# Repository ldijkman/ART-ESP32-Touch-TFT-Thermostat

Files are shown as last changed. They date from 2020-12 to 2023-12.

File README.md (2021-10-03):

# ART-ESP32-Touch-TFT-Thermostat

https://gofund.me/b8bf0b52

ART ESP32 SPI TFT Touch Clock Thermostat	

Manual by Touch TFT and WIFI(Future) clock thermostat

10 dollar DIY NEST thermostat	

Art, A Better NEST	

&&&&&&&&&&&&&&&&&&&&&&&&&&&&&&&&&&&&&&&&&&&&&&&&&&&&&&&&&&&&&&&&&&&&&&&&&&&&&&

GNU General Public License,

which basically means that you may freely copy, change, and distribute it,

but you may not impose any restrictions on further distribution,

and you must make the source code available.

&&&&&&&&&&&&&&&&&&&&&&&&&&&&&&&&&&&&&&&&&&&&&&&&&&&&&&&&&&&&&&&&&&&&&&&&&&&&&

https://oshwlab.com/l.dijkman/esp32-dev-kit-38-pin-to-spi-touch-tft	

https://github.com/ldijkman/ART-ESP32-Touch-TFT-Thermostat	

https://www.youtube.com/user/LuberthDijkman/videos

https://m.facebook.com/groups/2643123052617990

https://www.facebook.com/groups/esp32smartthermostat

#
## A Part of Art => HardWare is described @
## https://oshwlab.com/l.dijkman/esp32-dev-kit-38-pin-to-spi-touch-tft

Let's make ART smart!

.	

.	
#	
# Start ART	

@[youtube](http://youtu.be/qNYT64CaLEI)	

Simple Looks, No OverKill (Maybe make it SkinAble, For Those who like OverKill)

OK Distracted https://www.youtube.com/watch?v=0U4r2_s59qk



ECO mode = continu low heat setpoint energy saving setpoint (14C?)

NORMAL mode = continu heat comfortable setpoint (21C?)

AUTO mode = Switch heat temperature on programmed times with temperature

COOL mode = continu setpoint cooling airco/ventilator (25C?)

Maybe i will add a WoodStove Mode  = every hour? gas central water heating on for 5? minutes 

i mostly heat on a wood stove wich makes it colder in other parts of the house

i open the doors so that the heat can spread

But with stormy ice cold eastern wind / storm pipes can freeze in my old house

@[youtube](http://youtu.be/qNYT64CaLEI)	

ART_ESP32_Thermostat	

@[youtube](http://youtu.be/qNYT64CaLEI)	

Future (Could use some help on the WiFiManger & WebServer / HTML WebPage Part)

	

https://jsfiddle.net/luberth/b6y53cn0	

FullScreen https://jsfiddle.net/luberth/b6y53cn0/embedded/result/#Result	

#	
## First time EasyEDA.com and JLCPCB.com and LCSC.com == Perfect!	

My ESP32 TFT prototype test board, extra row of female connnectors for connecting devices test pinout

Only the holes ar a bit tight, but female row headers fit => Next time, double side copper PCB

And Ground the copper poor infill

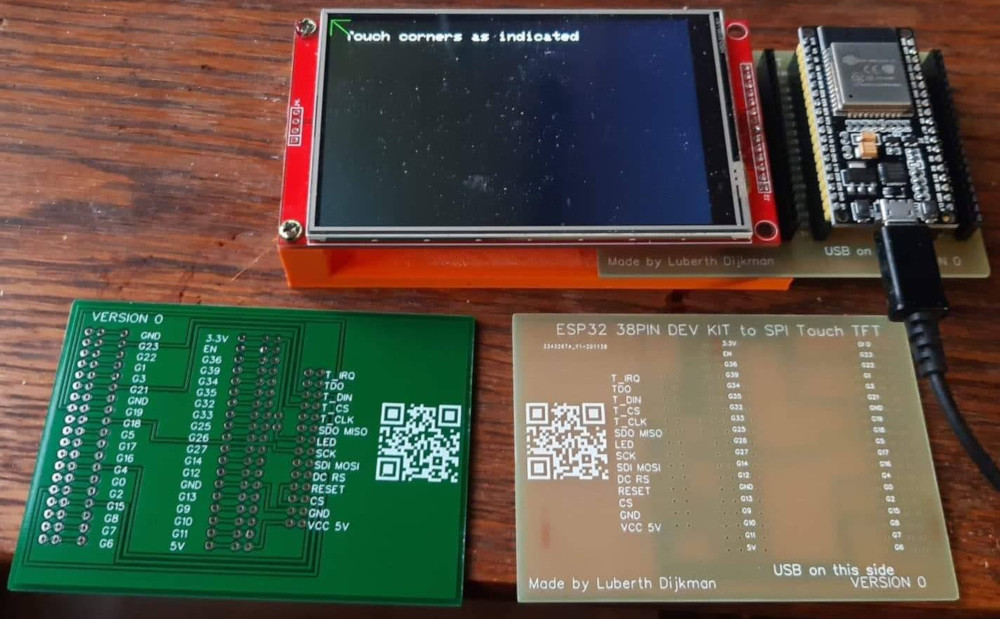
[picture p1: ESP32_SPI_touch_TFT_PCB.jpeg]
	

My ESP32 TFT prototype test board, extra row of female connnectors for connecting devices test pinout	

First time EasyEDA.com and JLCPCB.com and LCSC.com == Perfect!	

#
## DS3231 RTC with NTC Thermistor soldered onto power 

## sorry i switched to BME280 sensor temp. humid. barometer sensor == much better 

VCC on RTC DS3231 is 3.3V

Less Wires = Only a Signal wire from NTC Thermistor

NTC Connect => (-GND to VCC+3.3V) (VCC+3.3V to -GND) In Other Words Silkscreen print - should be + 

(This way its PULLDOWN) NTC Signal Line pulled down to ground
```diff
-Art's TFT screen will tell you how to connect the wires to ESP32 on startup

-On first boot Art's screen is Snowy for 20 seconds => I think Art is Formatting his Brain/Flash

```
ESP32 Note: Analog noise and fluctuences with analog read => multiread and capacitor 

https://docs.espressif.com/projects/esp-idf/en/latest/esp32/api-reference/peripherals/adc.html

Not so clear for me as DIY Tinker  => think they want a 0.1mf 100uf capacitor between signal and ground to damp the analog read

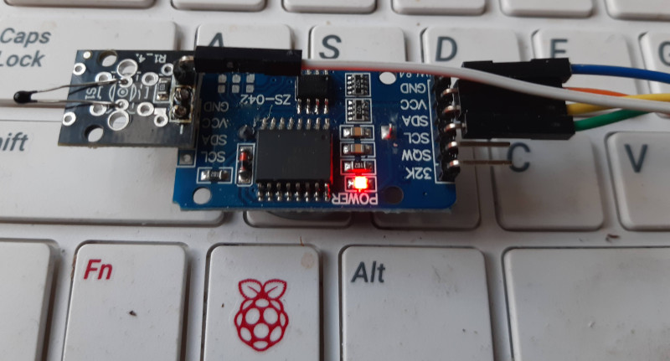
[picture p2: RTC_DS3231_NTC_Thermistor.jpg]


#
## TFT Backlight PWM cut the LED track to 3.3V

i have cut the LED track to 3.3V between the Pads

soldered a wire on the LED side pad

LED connected Wire connected to GPIO15 for the moment

Can now control the BackLight PWM from the screen/slidebar

in the LOOP{} is a hardcoded setting for now => dim screen if hour > ?? and < as ??

Jo's Energy Saver ;-)

a touch in top of screen in the blue rectangle => opens the settings menu

Blue border rectangle = Heating / Cooling is OFF

DutchOrange border Rectangle = The Heat is ON

IceBlue border Rectangle = Cooling is ON

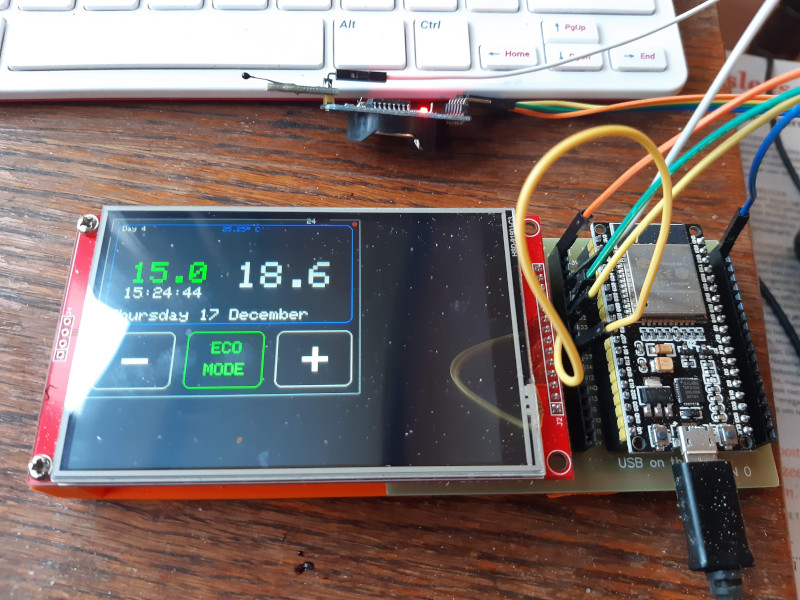
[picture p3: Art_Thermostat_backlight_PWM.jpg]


#
## Art output relais  heat & cool or single relais

the double relaiscoil is optical isolated swithed by optocoupler

the single relaiscoil is switched by transistor

a bit big relais for most off the time 24VAC CentralHeatingSystem switching

GND=GND

VCC = +5V (for the relais Coil) ESP32 +5VDC is comming from  USB

IN1, IN2 = if pulled low to GND => relais==ON (GPIO25 and GPIO26 from ESP32)

===== maybe Disconnect relais when programming ESP32  ======

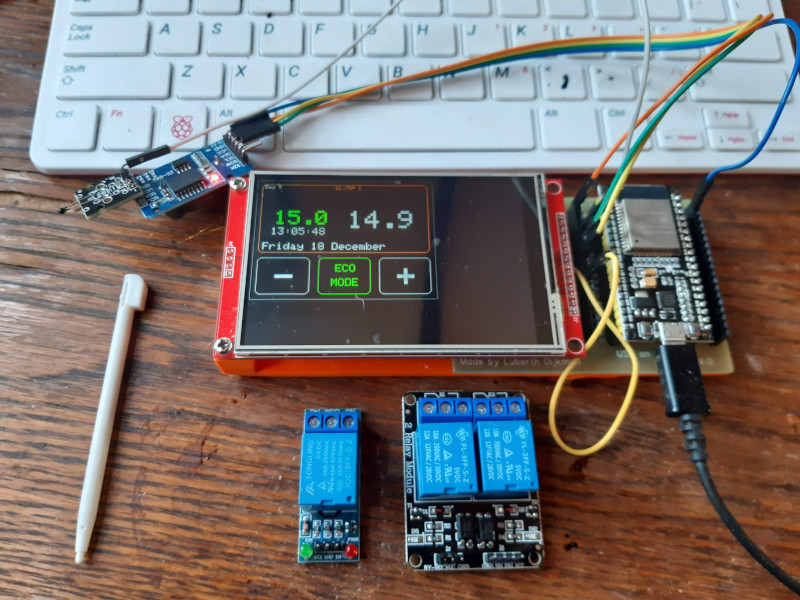
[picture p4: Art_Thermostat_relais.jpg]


#
## Art's Sensor BME280 Temperature, Humidity, Barometer (4Future)

ESP32 BME280 sensor test 

https://github.com/ldijkman/ART-ESP32-Touch-TFT-Thermostat/blob/main/test/ESP32_BME280_barometer_humidity_temperature_sensor_test.ino

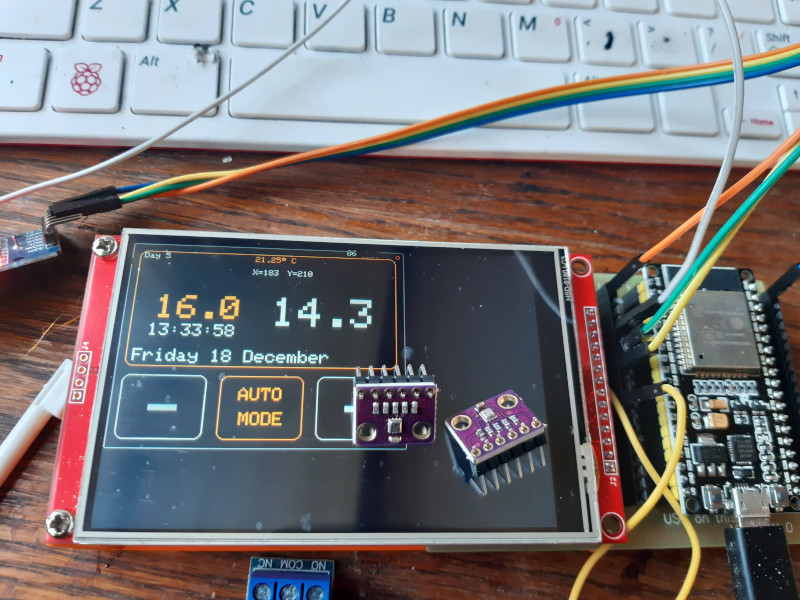
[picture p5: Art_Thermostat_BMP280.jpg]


#

BME280 humidity a scale makes vissible how whe ar doing with RV%

got my barometer pressure info from my pi webserver page http://84.107.155.75/

HE IS DAT HTTP://ARDUINO.Tk

## Art with Linear Humidity Comfort Scale 

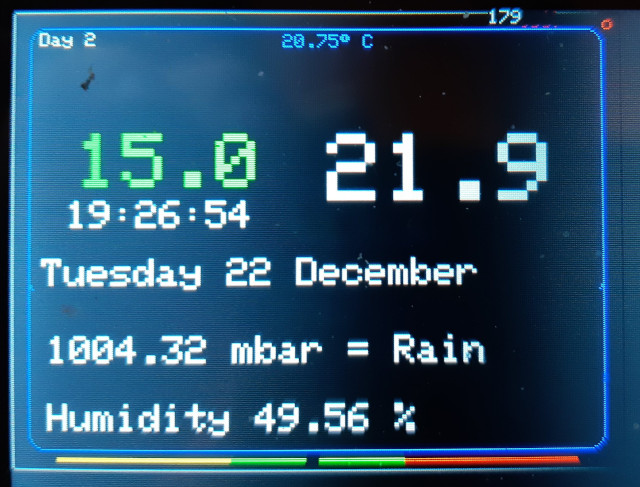
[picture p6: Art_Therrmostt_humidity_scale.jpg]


#
## Art with Linear BaroMeter and Humidity Comfort Scale

No it's not a slider, Art can not change the weather!

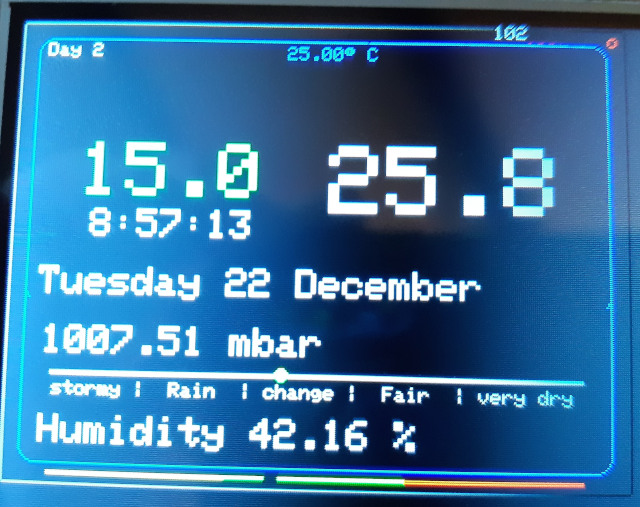
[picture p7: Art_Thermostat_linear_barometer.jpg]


#	
## This is wat your Arduino IDE should look like, Main File with the TAB files	

ART_ESP32_Thermostat_7_12_2020_ver2.ino => is the Main File	

The other *.INO files are included tab files (Should be in the same Directory as Main File)	

	

#
Have you got Arduino Experience, But don't know what to Do

WANTED, Boring Bored People or Students, I Could use some Help?!  ;-) 	

Make YourSelf UseFull!	

#

## It is Calendar Time, Free Printable Calender in many Languages	
## Print a Calendar for your Parents, GrandParents	
## http://sticker.tk/kalender.php
## http://arduino.tk
## http://PRINT-it.tk      
## http://PRINTit.tk

Art has a brand new home server http://www.arduino.tk

#
## maybe rtttl nokia ringtones for Art's Alarm 

http://Arduino.tk/rtttl/

http://Arduino.tk/rtttl/RTTTL_Tunes/ couple off thousands tunes 

We Dutch love Orange http://arduino.tk//rtttl/RTTTL_Tunes/play.php?file=Andr%E9+Hazes+-+Wij+Houden+Van+Oranje.txt

4 Art's BirthDay  http://sticker.tk/forum/rtttl/RTTTL_Tunes/play.php?file=Misc+-+Happy+Birthday+1.txt

dat mensen hier geld voor betaalden 
http://arduino.tk/rtttl/RTTTL_Tunes/play.php?file=xfiles.txt

#
### A Penny for Sharing My Thoughts?	

www.paypal.me/LDijkman	

# Art is now LIVE at http://Arduino.TK

# Help Art?!

https://m.facebook.com/groups/2643123052617990

https://www.facebook.com/groups/esp32smartthermostat

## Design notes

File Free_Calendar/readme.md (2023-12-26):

my mother had a paper memory

# Free printable calendar 2024

https://plnkr.co/plunk/2u0EyeybmaM9kdI8

Free_Printable_Calendar

https://plnkr.co/plunk/2u0EyeybmaM9kdI8

Screenshot from 2023-12-26 07-34-43

https://plnkr.co/plunk/2u0EyeybmaM9kdI8

http://PRINT-it.TK?v=dutch&year=2021

http://PRINT-it.TK?v=englisch&year=2021

more calendar versions/variants links in the video description https://youtu.be/yTHn8bYUQ8A

*.SKP is a web sketchup file a free online inbrowser 3D drawing program https://app.sketchup.com/app#

*.STL is for your Slic3r to generate G-Code for your 3d-printer

########################################################################################

SketchUp WEB OnLine inBrowser GETTING STARTED with SketchUp Free

BEGINNERS Start Here! https://www.youtube.com/watch?v=I_bJPNnO3HQ

How to create 3d model using sketchup web. (easy) https://youtu.be/4nKlk4asY6s .

Sketchup web 3d text tutorial https://www.youtube.com/watch?v=TQ_WKglHLcA

##########################################################################################

github STL 3D viewer 
https://github.com/ldijkman/ART-ESP32-Touch-TFT-Thermostat/blob/main/Free_Calendar/calendar_1_slic3r.stl

Want to make a 3d print / design for connecting / hang the printed calendar papers

 https://github.com/ldijkman/ART-ESP32-Touch-TFT-Thermostat/blob/main/Free_Calendar/calendar_1_(4).stl
 
 calendar_1_(4).stl with a steel / copper wire
 
 DutchOrange Hanger ;-)
 
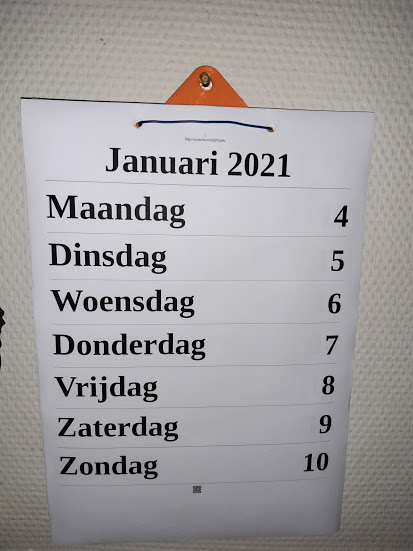
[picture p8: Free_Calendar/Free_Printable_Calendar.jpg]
 

 calendar_1_(4).stl with a steel / copper wire

http://PRINT-it.TK?v=dutch&year=2021

http://PRINT-it.TK?v=englisch&year=2021

kalender 1 day per a4 

http://sticker.tk/day_calender.php?v=dutch&year=2021

http://sticker.tk/day_calender.php?v=englisch&year=2021

http://sticker.tk/day_calender_portrait.php?v=dutch&year=2021

http://sticker.tk/day_calender_portrait.php?v=englisch&year=2021

week bigger days

http://sticker.tk/week_kalender.php?v=dutch&year=2021

http://sticker.tk/week_kalender.php?v=englisch&year=2021

week big days short

http://sticker.tk/week_kalender_afk.php?v=dutch&year=2021

http://sticker.tk/week_kalender_afk.php?v=englisch&year=2021

Print a Calendar for your Parents / GrandParents?! ;-)

Support this Free Printable Calendar Project ? http://paypal.me/LDijkman

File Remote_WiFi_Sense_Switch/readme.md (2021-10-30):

# latest esp8266 relais switch mdns config portal

No apps, no switching via china, just html webpage

https://github.com/ldijkman/ART-ESP32-Touch-TFT-Thermostat/blob/main/test/art_test_1/Remote_WiFi_Sense_Switch/ESP8266_MDNS_Hostname_relais_switch.ino.ino

https://github.com/ldijkman/ART-ESP32-Touch-TFT-Thermostat/blob/main/test/art_test_1/Remote_WiFi_Sense_Switch/ESP8266_MDNS_Hostname_relais_switch_list_other_on_webpa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

--

https://www.youtube.com/watch?v=sRqMcyHR-Ls

List automaticly scanned linked list other esp devices on network

If a new switch mdns http://***.local is added it automaticly appears in the linked list on all other esp devices webpage

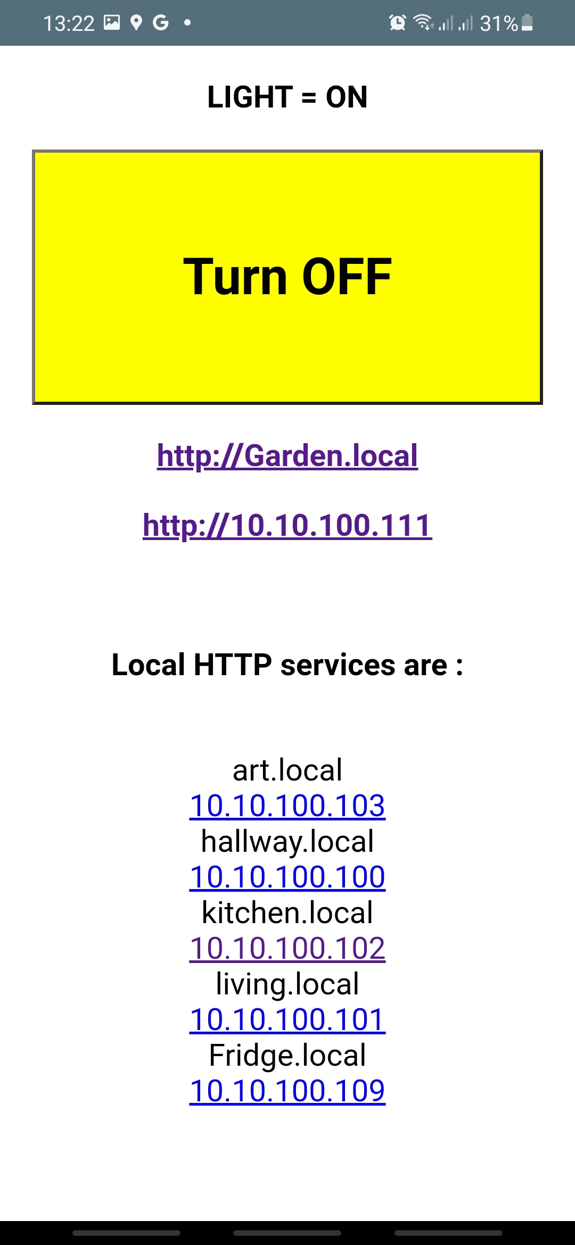
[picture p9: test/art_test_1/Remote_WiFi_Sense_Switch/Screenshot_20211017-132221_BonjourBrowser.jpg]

--
Tzapu wifimanager no hardcoded wifi settings and configurable mdns hostname and i/o

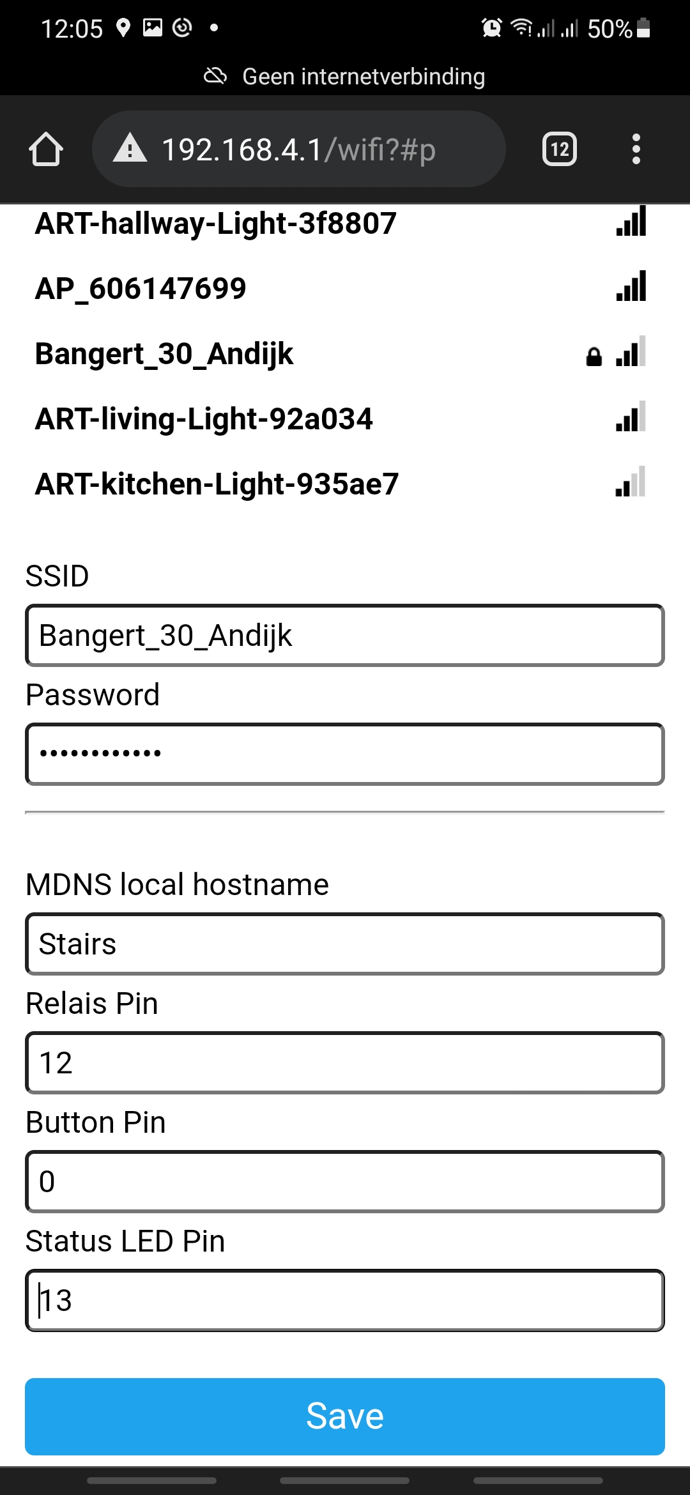
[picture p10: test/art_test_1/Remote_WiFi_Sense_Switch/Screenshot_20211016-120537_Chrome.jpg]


----
researching for a nice way to input and fast view automatice timed settings

slilebars needs scales and a timefield for each bar

touch and slide does not work properly on phone

but could be a nice fast graphical overview of switch times on a day in landscape mode on phone 

Hey Electra?! Turn on the lights automatic each monday fron 2:55 to 5:50?! ;-)

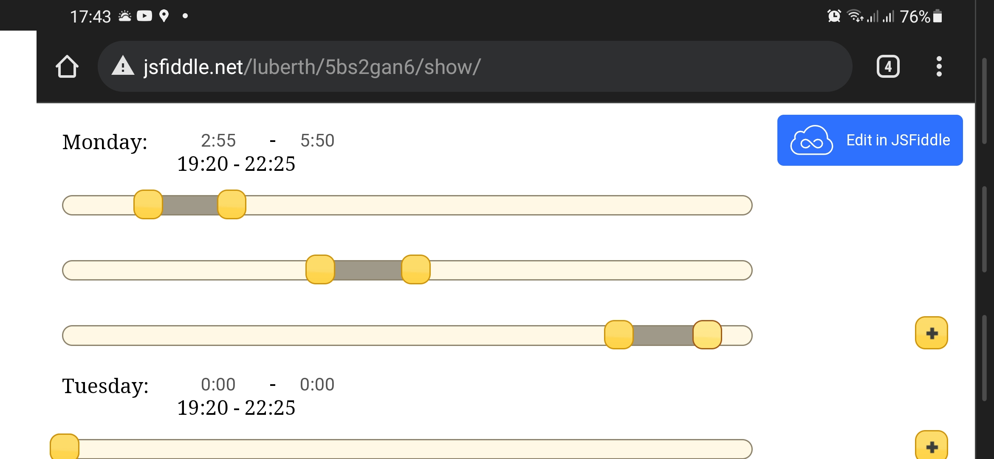
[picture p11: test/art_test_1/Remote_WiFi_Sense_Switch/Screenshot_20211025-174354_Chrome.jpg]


like this slider that the handles are not blocking view of the bar

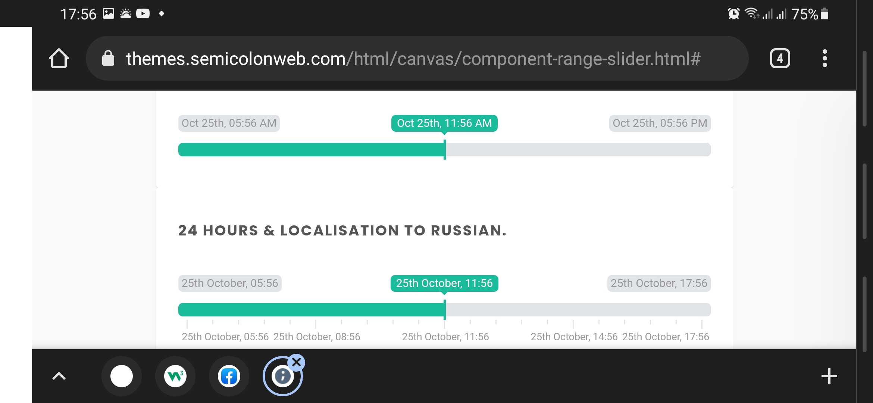
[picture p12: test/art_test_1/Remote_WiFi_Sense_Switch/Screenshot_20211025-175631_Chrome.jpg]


-

Nouislider works nice on phone

https://jsfiddle.net/user/leongersen/fiddles/

---

2 handles 0 to 24 hour https://jsfiddle.net/luberth/ow3zceyn/show/


---
-
-

remote relais lightswitch used esp8266 nodemcu / wemos d1 r1 mini with relais

on of switcted from touch buttons => settings menu 2 on art lcd touch screen

make timed remote light switch ???

Remote wifi sensors / switches for Art

reprogram sonoff switch why via chinese server = art is safe

sonoff is generic esp8266 module = esp01 programmer = plug programmer usb in pc with sonoff button pressed to get into programmimg mode 

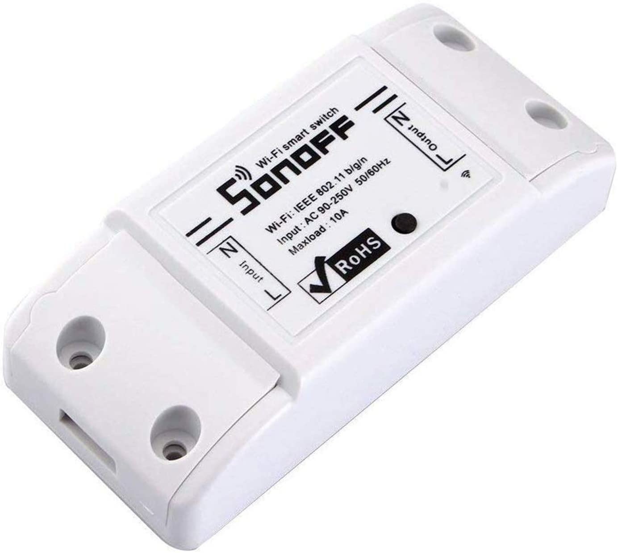
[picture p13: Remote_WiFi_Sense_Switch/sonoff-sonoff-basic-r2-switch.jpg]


Remote wifi sensors / switches for Art

temp sensors

timed lights

timed blinds / curtains

smoke detectors

pir sensors / light / alarm

switches

King Art has a Girlfriend named Electra

Hey Electra?!. Turn off the light in the DarkRoom?!

https://www.youtube.com/watch?v=XzO9jGPtrhc

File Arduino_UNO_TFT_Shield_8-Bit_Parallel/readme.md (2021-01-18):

Reuse that old arduino uno tft shield 8 bit parallel

uses a lot more io pins

is faster?

wil try this in the future

modifeid version of the thermostat will be here in the future

<h1>ReUse that old Arduino UNO / Mega Touch TFT Shield</h1>

it is possible to re use that old parallel tft shield

ILI9341 + ESP32 (Parallel) at blazing speeds

<a href="https://www.pangodream.es/ili9341-esp32-parallel" target="spain">https://www.pangodream.es/ili9341-esp32-parallel</a>
#
## looks like pin 21 22 are free for i2c ds3231 rtc an bme280

    <a href="https://github.com/Bodmer/TFT_eSPI/issues/448" target="bodmer">8-bit parallel 3.5 TFT LCD Shield + ESP32 -TouchScreen issue #448                        https://github.com/Bodmer/TFT_eSPI/issues/448</a>

sebbe2407 commented 3 days ago

Hi everyone...

i had the same issues with this 3,5" TFT LCD and wiring it to an ESP32 and making the TouchScreen work. 

However i managed to find a solution to the problem. Lets start with the wiring:

&&&&&&&&&&&&&&&&&&&&&&&&&&&&&&&&&&&&&&&&&&&&&&&&&&&&&&&&&&&&&&&&&&&&&&&&&&&&&&&&&&&&&&&&&&&&&&&&&&&&&&&&&&&&&&&&&&&&&&&&&&&&

Luberth => i think the => TFT LCD 5VDC can be left disconnected is NOT according to http://www.lcdwiki.com they say 3.3v can be left disconnected

Luberth => i think the => TFT LCD 3.3VDC should be an external +3.3VDC not from ESP32 LCD backlight power is too much for ESP32 voltage regulator

&&&&&&&&&&&&&&&&&&&&&&&&&&&&&&&&&&&&&&&&&&&&&&&&&&&&&&&&&&&&&&&&&&&&&&&&&&&&&&&&&&&&&&&&&&&&&&&&&&&&&&&&&&&&&&&&&&&&&&&&&&&&&&

#define TFT_CS 33

#define TFT_DC 15

#define TFT_RST 32

#define TFT_WR 4

#define TFT_RD 2

#define TFT_D0 12

#define TFT_D1 13

#define TFT_D2 26

#define TFT_D3 25

#define TFT_D4 17

#define TFT_D5 16

#define TFT_D6 27

#define TFT_D7 14

Next lets focus on the software side. 

In bodmers awesome library you have to comment/uncomment the right sections. 

The User_Setup.h file is pretty straight forward. 

My display used the ILI9488 processor and is run in 8 Bit parallel mode:

#define ILI9488_DRIVER

#define TFT_PARALLEL_8_BIT

When it came to the touchscreen i faced some difficulties. 

Since the display with 8 bit there is no dedicated "Touch Pin" like other displays use.

I decided to use a different library than @Bodmer (no front, still love you and the library <3). 

I used the ADAFRUIT Touchscreen library in extend:

#include <stdint.h>

#include "TouchScreen.h"

The Touchscreen sends us four different values if wired correctly. 

The X-Position, Y-Postition aswell as the pressure applied (XM, YM). 

These values are received via the following pins:

XP = TFT_D0

YP = TFT_CS

XM = TFT_DC

YM = TFT_D1

This did the trick for me and made the touchscreendemo example work for me.

Maybe this helps some people ....

Have a good one ! :) @gvfo5

    <a href="https://github.com/Bodmer/TFT_eSPI/issues/539" target="bodmer">8-bit parallel 3.5" TFT LCD ILI9486 does not work #539                                   https://github.com/Bodmer/TFT_eSPI/issues/539</a>



During testing, you can connect TFT 3V3 pin directly to ESP32 3V3 pin, 

but do it only during a short period of time because the current drawn by the screen LEDs is 134mA 

and you will notice how the LEDs and the Development Board voltage limiter will become hot.



During testing, you can connect TFT 3V3 pin directly to ESP32 3V3 pin,

but do it only during a short period of time because the current drawn by the screen LEDs is 134mA

and you will notice how the LEDs and the Development Board voltage limiter will become hot.

<a href="https://www.pangodream.es/ili9341-esp32-parallel" target="spain">https://www.pangodream.es/ili9341-esp32-parallel</a>

<iframe width="640" height="480" src="https://www.youtube.com/embed/dhQjDKtNi58?rel=0" frameborder="0" allow="accelerometer; autoplay; clipboard-write; encrypted-media; gyroscope; picture-in-picture" allowfullscreen></iframe>

<a href="https://www.pangodream.es/ili9341-esp32-parallel" target="spain">https://www.pangodream.es/ili9341-esp32-parallel</a>

Previet, Spassiba  Андрей Ушаков
<iframe width="640" height="480" src="https://www.youtube.com/embed/56BZ-v4ings?rel=0" frameborder="0" allow="accelerometer; autoplay; clipboard-write; encrypted-media; gyroscope; picture-in-picture" allowfullscreen></iframe>

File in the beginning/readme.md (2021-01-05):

In the Beginning

https://youtu.be/LTelO4141W8 ;-)

The start of Art.

 Original File From / By Fabio Mastrotto 

This video started it all for me = Arduino Nano 
https://www.youtube.com/watch?v=CM0h_ad7ETU

Art's Root's

Art was Cloned Around About the Fourth of July 2020

Grown up from Arduino Uno with TFT shield

To Mega 2560 to Mega2560 with onboard ESP8266

And now, Art is on its Best on an ESP32 and SPI Touch TFT 

Better then Ever

Art still has to learn a lot, like WiFi

and remember Things

# It is Calendar Time
# Print a Calendar for your Parents, GrandParents
http://www.PRINT-it.TK
# http://www.PRINT-it.TK

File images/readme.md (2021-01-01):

should  take images from root

but they are linked everywhere

stupid me

https://www.youtube.com/c/criiminal9090espectraCode/featured  =>   https://youtu.be/zL7twU3xYio



# http://www.Arduino.TK

Art Live video server old phone

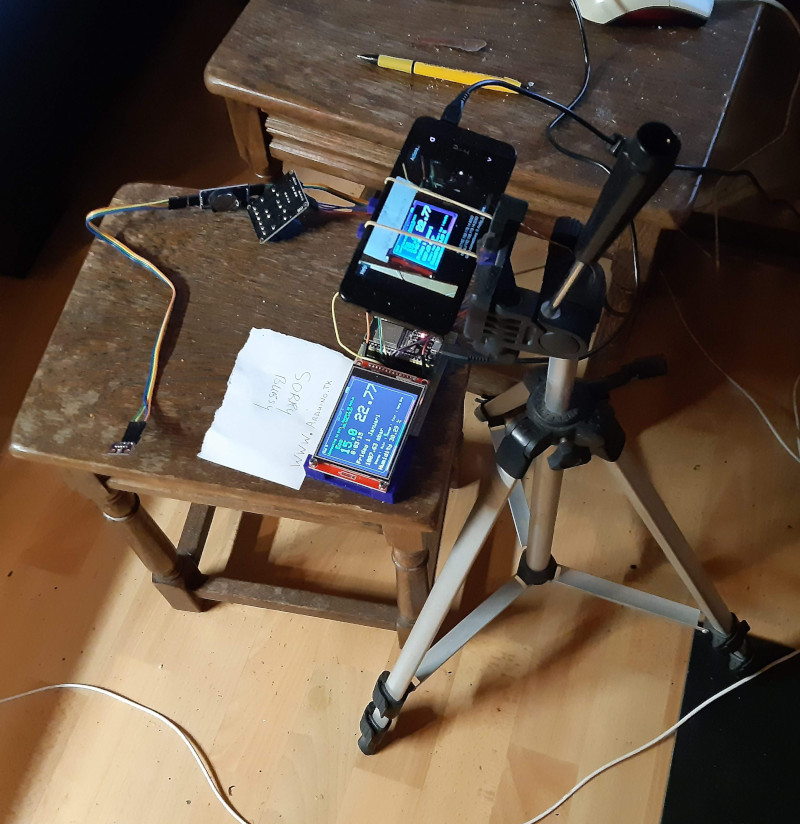
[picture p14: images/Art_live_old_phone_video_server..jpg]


# http://www.Arduino.TK

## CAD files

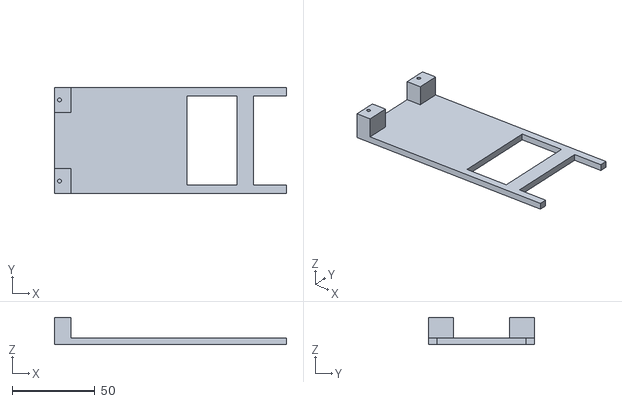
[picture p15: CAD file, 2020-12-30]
3D_Prints for Art/3.2inch.stl
140.0 x 64.0 x 16.5

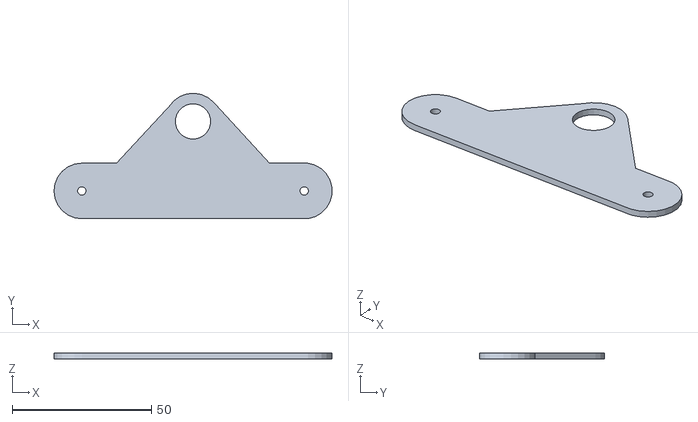
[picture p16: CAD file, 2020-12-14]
Free_Calendar/calendar_1_(4).stl
100.0 x 45.1 x 2.00

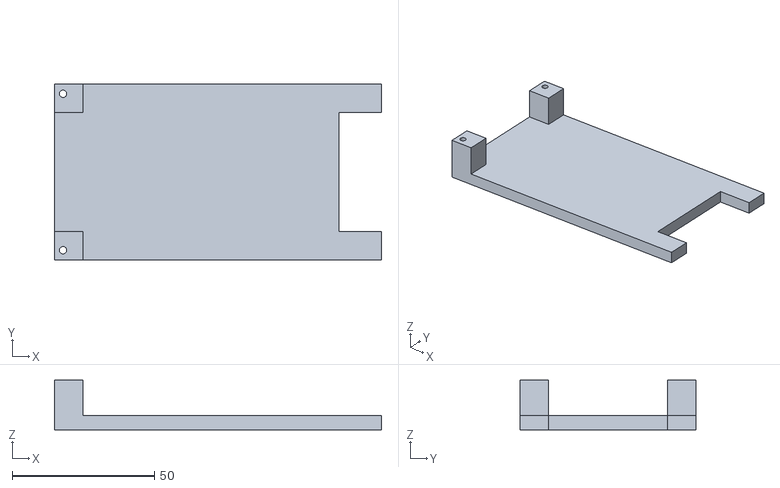
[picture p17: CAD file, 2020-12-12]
3D_Prints for Art/TFT_TABLE_Version2 (1).stl
115.0 x 62.0 x 17.5

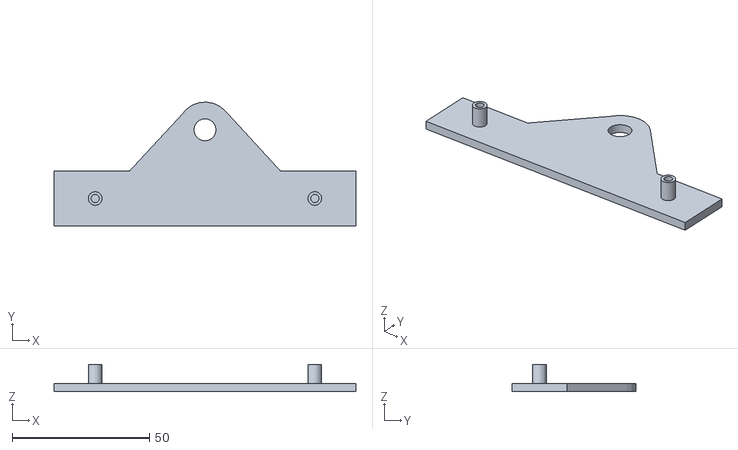
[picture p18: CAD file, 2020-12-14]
Free_Calendar/calendar_1_slic3r.stl
110.0 x 45.1 x 10.0

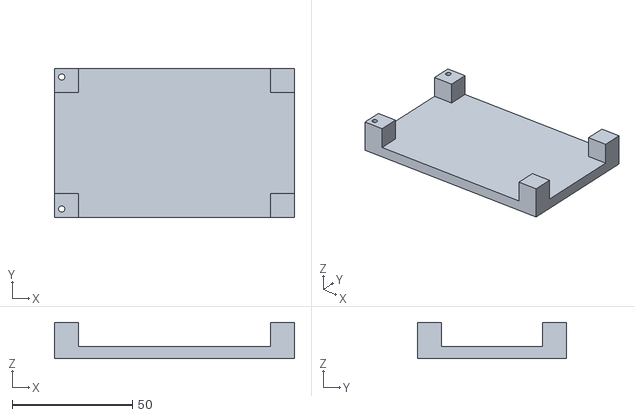
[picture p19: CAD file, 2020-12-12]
3D_Prints for Art/tft_table.stl
100.0 x 62.0 x 15.0

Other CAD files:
3D_Prints for Art/3.2inch.skp
3D_Prints for Art/TFT_TABLE_Version2.skp
3D_Prints for Art/tft_table.skp
Free_Calendar/calendar_1.skp
Free_Calendar/calendar_1_(4).skp

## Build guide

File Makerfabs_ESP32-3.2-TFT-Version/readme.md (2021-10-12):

-------------------------------------------------

do not like makerfabs

ordered one

payed for it

never recieved

---------------------------------------------------------------------

Makerfabs_ESP32-3.2-TFT-Version

3.2 inch touch tft with esp32 and camera

Art Thermostat code fo this hardware

FUTURE Project

http://www.makerfabs.com/esp32-3.2-inch-tft-touch-with-camera.html

https://www.makerfabs.com/esp32-3.5-inch-tft-touch-resistive-with-camera.html

https://www.makerfabs.com/esp32-3.5-inch-tft-touch-capacitive-with-camera.html

https://youtu.be/ep8f4jEe2gE

https://youtu.be/lHzoYHrOLqY

https://youtu.be/ZTmOsALh8UE

https://youtu.be/ovktqwGp7kQ

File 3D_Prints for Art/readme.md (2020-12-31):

3D_Prints for Art

File *.SKP = Sketchup File = Free Online inBrowser drawing, Works well on my pi400 now

https://app.sketchup.com/app#   => Can Save / Export to *.STL for Slic3r for G-Code => 3D Printing

########################################################################################

SketchUp WEB OnLine inBrowser GETTING STARTED with SketchUp Free

BEGINNERS Start Here! https://www.youtube.com/watch?v=I_bJPNnO3HQ

How to create 3d model using sketchup web. (easy) https://youtu.be/4nKlk4asY6s .

Sketchup web 3d text tutorial https://www.youtube.com/watch?v=TQ_WKglHLcA

##########################################################################################

.

Click on the

https://github.com/ldijkman/ART-ESP32-Touch-TFT-Thermostat/blob/main/3D_Prints%20for%20Art/tft_table.stl

and be surprised => a github 3D viewer (i was ;-)

.

DutchOrange, Wander wat Prusa thinks of that Orange ;-)

.

ScreenSize info from http://www.lcdwiki.com/Main_Page

.

Used an old floppy drive FlatCable, Not the correct number of pins 

if you use the same holes on both side its no problem

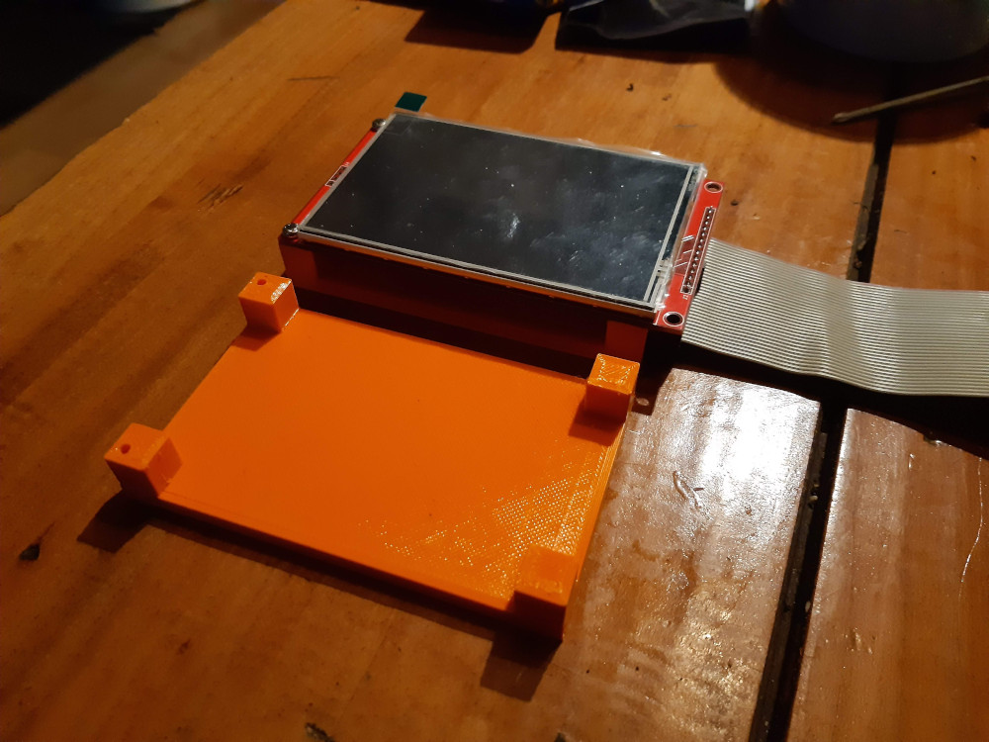
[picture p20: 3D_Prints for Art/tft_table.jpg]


 version 2
 
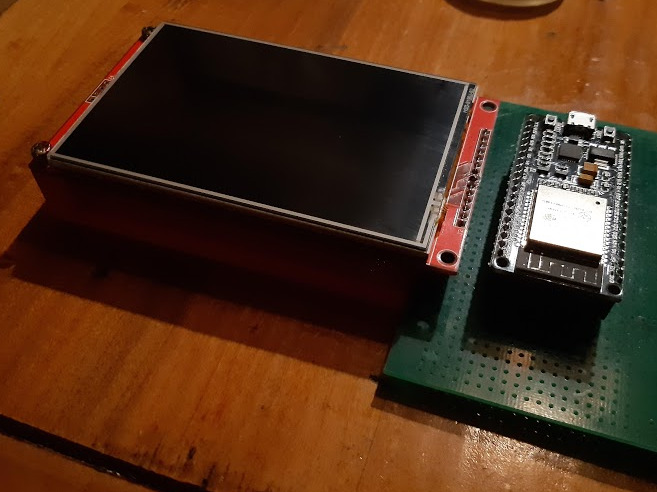
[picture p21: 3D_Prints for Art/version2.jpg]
 

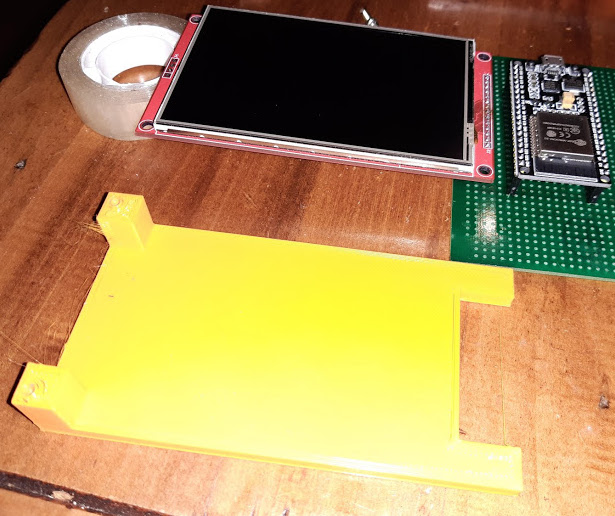
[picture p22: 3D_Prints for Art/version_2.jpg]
  

##  https://oshwlab.com/l.dijkman/esp32-dev-kit-38-pin-to-spi-touch-tft

https://github.com/ldijkman/ART-ESP32-Touch-TFT-Thermostat/blob/main/3D_Prints%20for%20Art/3.2inch.stl

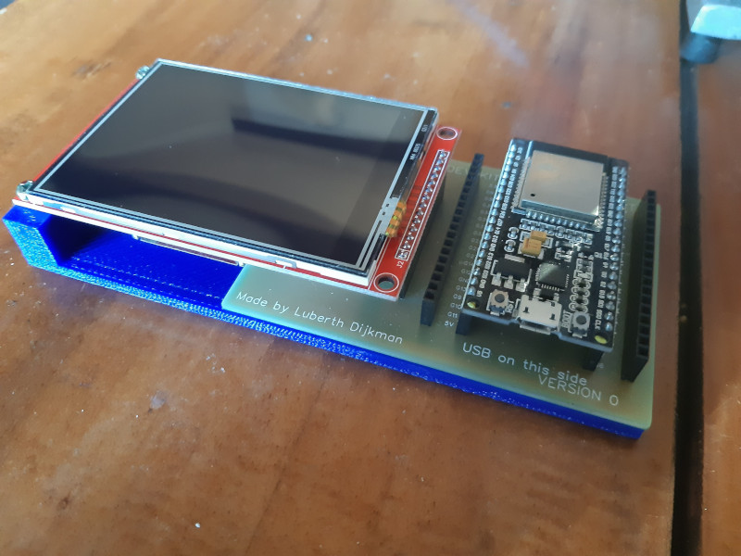
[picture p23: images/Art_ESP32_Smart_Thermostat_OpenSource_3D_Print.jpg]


https://github.com/ldijkman/ART-ESP32-Touch-TFT-Thermostat/blob/main/3D_Prints%20for%20Art/3.2inch.stl



# It is Calendar Time
# Print a Calendar for your Parents, GrandParents
# http://www.PRINT-it.TK

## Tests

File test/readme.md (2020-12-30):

# http://www.Arduino.TK

ESP32 Test programs, Test programs for ART Thermostat

https://github.com/ldijkman

https://github.com/ldijkman/ART-ESP32-Touch-TFT-Thermostat

https://oshwlab.com/l.dijkman/esp32-dev-kit-38-pin-to-spi-touch-tft

https://jsfiddle.net/luberth/b6y53cn0 FullScreen https://jsfiddle.net/luberth/b6y53cn0/embedded/result/#Result

https://www.youtube.com/user/LuberthDijkman

https://m.facebook.com/luberth.dijkman

@[youtube](http://youtu.be/qNYT64CaLEI)



@[youtube](http://youtu.be/qNYT64CaLEI)

ART_ESP32_Thermostat

@[youtube](http://youtu.be/qNYT64CaLEI)



https://jsfiddle.net/luberth/b6y53cn0

FullScreen https://jsfiddle.net/luberth/b6y53cn0/embedded/result/#Result

Coffee keeps me going

https://www.paypal.com/pools/c/8amUN5rgb9

www.paypal.me/LDijkman

#
#
### Arduino Experience, But dont know what to do?     

### WANTED, Boring Bored People or Students, I could use some help?!  ;-)

### Make YourSelf UseFull!

#                     
#                     
# It is Calendar Time
# Print a Calendar for your Parents, GrandParents
#### http://www.sticker.tk

# http://www.PRINT-it.TK

# http://www.Arduino.TK

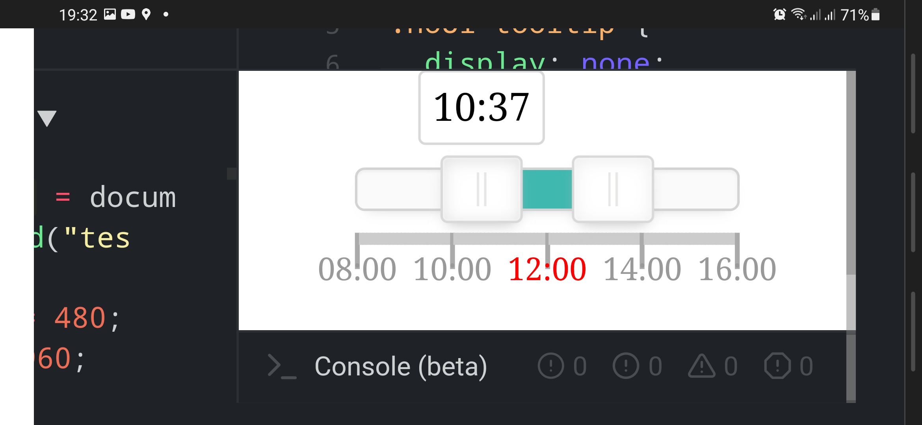
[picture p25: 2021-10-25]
test/art_test_1/Remote_WiFi_Sense_Switch/Screenshot_20211025-193210_Chrome.jpg

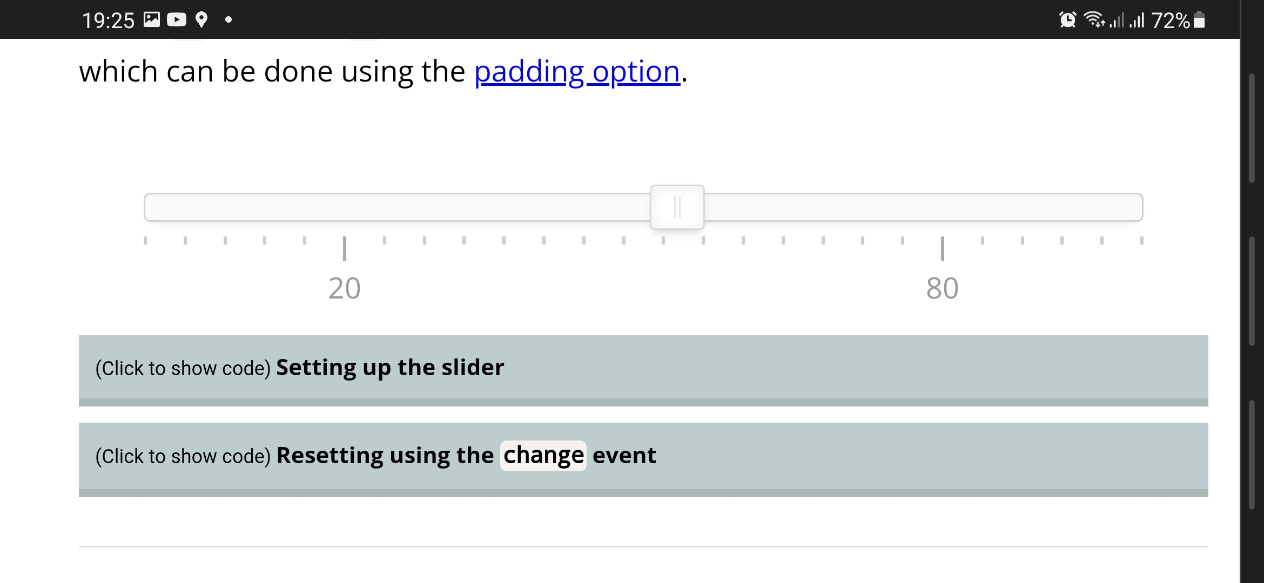
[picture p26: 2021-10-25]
test/art_test_1/Remote_WiFi_Sense_Switch/Screenshot_20211025-192551_Chrome.jpg

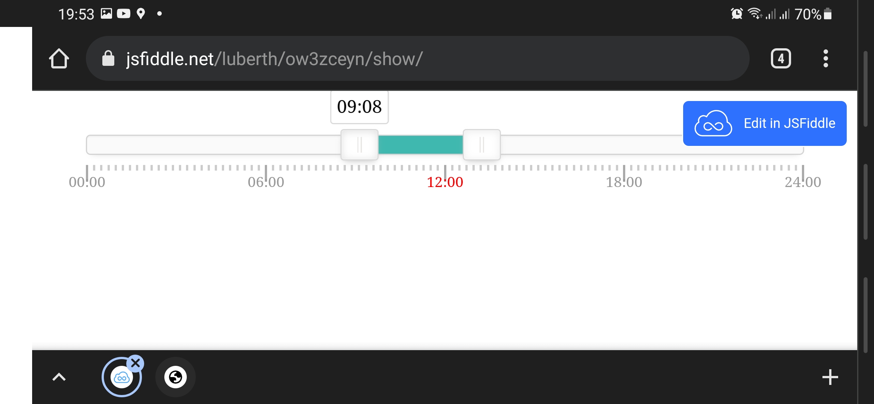
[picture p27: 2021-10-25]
test/art_test_1/Remote_WiFi_Sense_Switch/Screenshot_20211025-195305_Chrome.jpg

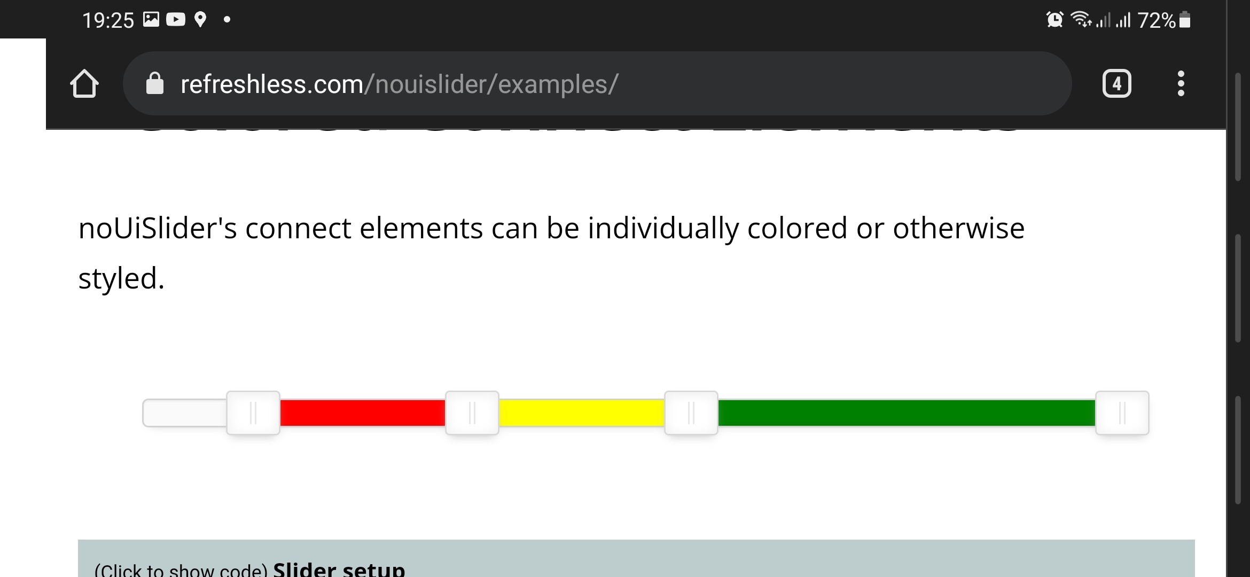
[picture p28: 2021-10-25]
test/art_test_1/Remote_WiFi_Sense_Switch/Screenshot_20211025-192515_Chrome.jpg

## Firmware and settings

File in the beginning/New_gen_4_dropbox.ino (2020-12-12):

//
// Arduino Uno, Nano, Mega, TFT Touch Thermostat
//
// Single File Code from / by Fabio Mastrotto 
// https://www.youtube.com/watch?v=CM0h_ad7ETU
//
// This video started it all for me
// https://github.com/ldijkman/ART-ESP32-Touch-TFT-Thermostat
//
// The OverUse of SetRotation() changes => drives you crazy
// Possible because of display and touch locations with AdaFruit Graphic / Touch librarys
// i like TFT_eSPI TFT Touch Graphic Library
//
// only 1 analog  read for temperate each time => Makes Actual Temperature display jumpy
// better do 100+ reads and divide by 100+

//#####################################################################################

// Original Arduino IDE SourceCode by Fabio Mastrotto 
// Single File Code from / by Fabio Mastrotto 
// https://www.youtube.com/watch?v=CM0h_ad7ETU
#include <Adafruit_GFX.h>    // Core graphics library
#include <Adafruit_TFTLCD.h> // Hardware-specific library
#include <TouchScreen.h>
#include <math.h>
#if defined(__SAM3X8E__)
    #undef __FlashStringHelper::F(string_literal)
    #define F(string_literal) string_literal
#endif
#define YP A3
#define XM A2
#define YM 9
#define XP 8
#define TS_MINX 120
#define TS_MAXX 900
#define TS_MINY 70
#define TS_MAXY 920
TouchScreen ts = TouchScreen(XP, YP, XM, YM, 300);
#define LCD_CS A3
#define LCD_CD A2
#define LCD_WR A1
#define LCD_RD A0
#define LCD_RESET A4

// Assign human-readable names to some common 16-bit color values:
#define  BLACK   0x0000
#define BLUE    0x001F
#define RED     0xF800
#define GREEN   0x07E0
#define CYAN    0x07FF
#define MAGENTA 0xF81F
#define YELLOW  0xFFE0
#define WHITE   0xFFFF
// Color definitions
#define ILI9341_BLACK       0x0000      /*   0,   0,   0 */
#define ILI9341_NAVY        0x000F      /*   0,   0, 128 */
#define ILI9341_DARKGREEN   0x03E0      /*   0, 128,   0 */
#define ILI9341_DARKCYAN    0x03EF      /*   0, 128, 128 */
#define ILI9341_MAROON      0x7800      /* 128,   0,   0 */
#define ILI9341_PURPLE      0x780F      /* 128,   0, 128 */
#define ILI9341_OLIVE       0x7BE0      /* 128, 128,   0 */
#define ILI9341_LIGHTGREY   0xC618      /* 192, 192, 192 */
#define ILI9341_DARKGREY    0x7BEF      /* 128, 128, 128 */
#define ILI9341_BLUE        0x001F      /*   0,   0, 255 */
#define ILI9341_GREEN       0x07E0      /*   0, 255,   0 */
#define ILI9341_CYAN        0x07FF      /*   0, 255, 255 */
#define ILI9341_RED         0xF800      /* 255,   0,   0 */
#define ILI9341_MAGENTA     0xF81F      /* 255,   0, 255 */
#define ILI9341_YELLOW      0xFFE0      /* 255, 255,   0 */
#define ILI9341_WHITE       0xFFFF      /* 255, 255, 255 */
#define ILI9341_ORANGE      0xFD20      /* 255, 165,   0 */
#define ILI9341_GREENYELLOW 0xAFE5      /* 173, 255,  47 */
#define ILI9341_PINK        0xF81F
Adafruit_TFTLCD tft(LCD_CS, LCD_CD, LCD_WR, LCD_RD, LCD_RESET);
const int pin = A5;
double celsius = 0;
float millivolts;
int sensor; 
int contatore = 0;
int caldaia_s = 0;
int old_caldaia_s = 0;
int eco_m = 0;
int lettura_seriale;
double beginTemperature = 18;
double U_D_T = 0.5;
double memoria;
double eco_m_temp;
void setup(void) {
  Serial.begin(9600);
  tft.reset();  
  uint16_t identifier = tft.readID();
  if(identifier == 0x9325) {
    Serial.println(F("Found ILI9325 LCD driver"));
  } else if(identifier == 0x9328) {
    Serial.println(F("Found ILI9328 LCD driver"));
  } else if(identifier == 0x4535) {
    Serial.println(F("Found LGDP4535 LCD driver"));
  }else if(identifier == 0x7575) {
    Serial.println(F("Found HX8347G LCD driver"));
  } else if(identifier == 0x9341) {
    Serial.println(F("Found ILI9341 LCD driver"));
  } else if(identifier == 0x8357) {
    Serial.println(F("Found HX8357D LCD driver"));
  } else if(identifier==0x0101)
  {     
      identifier=0x9341;
       Serial.println(F("Found 0x9341 LCD driver"));
  }else {
    Serial.print(F("Unknown LCD driver chip: "));
    Serial.println(identifier, HEX);
    Serial.println(F("If using the Adafruit 2.8\" TFT Arduino shield, the line:"));
    Serial.println(F("  #define USE_ADAFRUIT_SHIELD_PINOUT"));
    Serial.println(F("should appear in the library header (Adafruit_TFT.h)."));
    Serial.println(F("If using the breakout board, it should NOT be #defined!"));
    Serial.println(F("Also if using the breakout, double-check that all wiring"));
    Serial.println(F("matches the tutorial."));
    identifier=0x9341;   
  }
  sensor = analogRead(pin);
  millivolts = ( sensor/1023.0)*3300;
  celsius =millivolts/10; 
  tft.begin(identifier);
  tft.setRotation(3);
  tft.fillScreen(WHITE);
  tft.setCursor(102, 105);
  tft.setTextColor(ILI9341_LIGHTGREY);  tft.setTextSize(3);
  tft.println("Wellcome");
  delay(2000);
  tft.fillScreen(BLACK);
  tft.setCursor(102, 105);
  tft.setTextColor(ILI9341_LIGHTGREY);  tft.setTextSize(3);
  tft.println("designed"); 
  delay(300);
  tft.fillScreen(WHITE); 
  tft.setCursor(102, 105);
  tft.setTextColor(ILI9341_LIGHTGREY);  tft.setTextSize(3);
  tft.println("   by");
  delay(300);
  tft.fillScreen(BLACK);
  tft.setCursor(102, 105);
  tft.setTextColor(ILI9341_LIGHTGREY);  tft.setTextSize(3);
  tft.println("  SPM");   
  pinMode(13, OUTPUT);
  delay(1000);
  tft.setRotation(2);
  tft.fillScreen(BLACK);
  tft.drawRect(10, 10, 70, 90, ILI9341_LIGHTGREY);
  tft.drawRect(10, 115, 70, 90, ILI9341_LIGHTGREY);
  tft.drawRect(10, 220, 70, 90, ILI9341_LIGHTGREY);
  tft.drawRect(90, 10, 140, 300, ILI9341_LIGHTGREY);
 tft.setRotation(3);
  tft.setCursor(41, 175);
  tft.setTextColor(ILI9341_LIGHTGREY);  tft.setTextSize(6);
  tft.println("-");
  tft.setCursor(251, 175);
  tft.setTextColor(ILI9341_LIGHTGREY);  tft.setTextSize(6);
  tft.println("+");
  tft.setCursor(144, 173);
  tft.setTextColor(ILI9341_LIGHTGREY);  tft.setTextSize(2);
  tft.println("ECO");
  tft.setCursor(137, 200);
  tft.setTextColor(ILI9341_LIGHTGREY);  tft.setTextSize(2);
  tft.println("MODE");
  tft.setCursor(25, 35);
  tft.setTextColor(ILI9341_LIGHTGREY);  tft.setTextSize(2);
  tft.println("Temp. amb.:         C");
  tft.setCursor(25, 75);
  tft.setTextColor(ILI9341_LIGHTGREY);  tft.setTextSize(2);
  tft.println("Temp. imp.:         C");
  tft.setCursor(175, 75);
  tft.setTextColor(ILI9341_LIGHTGREY);  tft.setTextSize(2);
  tft.println(beginTemperature);
  tft.setCursor(175, 35);
  tft.setTextColor(ILI9341_LIGHTGREY);  tft.setTextSize(2);
  tft.println(celsius);
  tft.setCursor(25, 115);
  tft.setTextColor(ILI9341_LIGHTGREY);  tft.setTextSize(2);
  tft.println("Stato caldaia:");
}
#define MINPRESSURE 10
#define MAXPRESSURE 1000
void loop(){
  digitalWrite(13, HIGH);
  TSPoint p = ts.getPoint();
  digitalWrite(13, LOW);
  pinMode(XM, OUTPUT);
  pinMode(YP, OUTPUT);
  sensor = analogRead(pin);
  millivolts = ( sensor/1023.0)*3300; 
  celsius =millivolts/10; 
  contatore=contatore+1;
  if (contatore>=2000){
    tft.setRotation(2);
    tft.fillRect(186, 170, 25, 75, BLACK);
    tft.setRotation(3);          
    tft.setCursor(175, 35);
    tft.setTextColor(ILI9341_LIGHTGREY);  tft.setTextSize(2);
    tft.println(celsius);
    contatore=0;
  }
  if (p.z > MINPRESSURE && p.z < MAXPRESSURE) {
    tft.setRotation(2);
    p.x = map(p.x, TS_MINX, TS_MAXX, tft.width(), 0);
    p.y = (tft.height()-map(p.y, TS_MINY, TS_MAXY, tft.height(), 0));
    if (p.x > 10 && p.x < 80) {
          if (p.y > 10 && p.y < 100) {
          beginTemperature= (beginTemperature-U_D_T);
          //Serial.print(("5"));
          //tft.setRotation(2);
          tft.fillRect(145, 170, 25, 75, BLACK);
          tft.setRotation(3);
          tft.setCursor(175, 75);
          tft.setTextColor(ILI9341_LIGHTGREY);  tft.setTextSize(2);
          tft.println(beginTemperature);
          delay(100);
        }
        if (p.y > 115 && p.y < 205) {
          tft.setRotation(3);
          if (eco_m==0){
            eco_m=1;            
            tft.setCursor(144, 173);
            tft.setTextColor(ILI9341_DARKGREEN);  tft.setTextSize(2);
            tft.println("ECO");
            tft.setCursor(137, 200);
            tft.setTextColor(ILI9341_DARKGREEN);  tft.setTextSize(2);
            tft.println("MODE");
            memoria = beginTemperature;
            eco_m_temp = beginTemperature-3;

            tft.setRotation(2);
            tft.fillRect(145, 15, 25, 280, BLACK);
            tft.setRotation(3);
            tft.setCursor(25, 75);
            tft.setTextColor(ILI9341_LIGHTGREY);  tft.setTextSize(2);
            tft.println("Eco Temp.:          C");
            tft.setCursor(175, 75);
            tft.setTextColor(ILI9341_LIGHTGREY);  tft.setTextSize(2);
            tft.println(eco_m_temp);  
            delay(1000);
            goto OUTSUB;
          }
          if (eco_m==1){
            eco_m=0;
            tft.setCursor(144, 173);
            tft.setTextColor(ILI9341_LIGHTGREY);  tft.setTextSize(2);
            tft.println("ECO");
            tft.setCursor(137, 200);
            tft.setTextColor(ILI9341_LIGHTGREY);  tft.setTextSize(2);
            tft.println("MODE");
            beginTemperature = memoria;
            tft.setRotation(2);
            tft.fillRect(145, 15, 25, 280, BLACK);
            tft.setRotation(3);
            tft.setCursor(25, 75);
            tft.setTextColor(ILI9341_LIGHTGREY);  tft.setTextSize(2);
            tft.println("Temp. imp.:         C");
            tft.setCursor(175, 75);
            tft.setTextColor(ILI9341_LIGHTGREY);  tft.setTextSize(2);
            tft.println(beginTemperature);
            delay(1000);
            goto OUTSUB;
          }       
        }        
        if (p.y > 220 && p.y < 310) {
          beginTemperature= (beginTemperature+U_D_T);
          //Serial.print(("4"));
          //tft.setRotation(2);
          tft.fillRect(145, 170, 25, 75, BLACK);
          tft.setRotation(3);
          tft.setCursor(175, 75);
          tft.setTextColor(ILI9341_LIGHTGREY);  tft.setTextSize(2);
          tft.println(beginTemperature);
          delay(100);
        }
      }
    }
OUTSUB:
  if (beginTemperature>30){
    beginTemperature=30;
    tft.setRotation(2);
    tft.fillRect(145, 170, 25, 75, BLACK);
    delay(600);
    tft.setRotation(3);
    tft.setCursor(175, 75);
    tft.setTextColor(RED);  tft.setTextSize(2);
    tft.println(" MAX");
    delay(600); 
    tft.setRotation(2);
    tft.fillRect(145, 170, 25, 75, BLACK);
    delay(600);
    tft.setRotation(3);
    tft.setCursor(175, 75);
    tft.setTextColor(RED);  tft.setTextSize(2);
    tft.println(" MAX");
    delay(600); 
    tft.setRotation(2);
    tft.fillRect(145, 170, 25, 75, BLACK);
    delay(600);
    tft.setRotation(3);
    tft.setCursor(175, 75);
    tft.setTextColor(RED);  tft.setTextSize(2);
    tft.println(" MAX");
    delay(600); 
    tft.setRotation(2);
    tft.fillRect(145, 170, 25, 75, BLACK);
    delay(600);
    tft.setRotation(3);
    tft.setCursor(175, 75);
    tft.setTextColor(ILI9341_LIGHTGREY);  tft.setTextSize(2);
    tft.println(beginTemperature);
   }
  if (beginTemperature<10){
    beginTemperature=10;
    tft.setRotation(2);
    tft.fillRect(145, 170, 25, 75, BLACK);
    delay(600);
    tft.setRotation(3);
    tft.setCursor(175, 75);
    tft.setTextColor(BLUE);  tft.setTextSize(2);
    tft.println(" MIN");
    delay(600); 
    tft.setRotation(2);
    tft.fillRect(145, 170, 25, 75, BLACK);
    delay(600);
    tft.setRotation(3);
    tft.setCursor(175, 75);
    tft.setTextColor(BLUE);  tft.setTextSize(2);
    tft.println(" MIN");
    delay(600); 
    tft.setRotation(2);
    tft.fillRect(145, 170, 25, 75, BLACK);
    delay(600);
    tft.setRotation(3);
    tft.setCursor(175, 75);
    tft.setTextColor(BLUE);  tft.setTextSize(2);
    tft.println(" MIN");
    delay(600); 
    tft.setRotation(2);
    tft.fillRect(145, 170, 25, 75, BLACK);
    delay(600);
    tft.setRotation(3);
    tft.setCursor(175, 75);
    tft.setTextColor(ILI9341_LIGHTGREY);  tft.setTextSize(2);
    tft.println(beginTemperature);
    }
  if (eco_m==0){
    if (celsius>(beginTemperature+1.5)){
    caldaia_s = 0;
    }               
  if (celsius<(beginTemperature-1.5)){
    caldaia_s = 1;
    }
  }
  if (eco_m==1){
    if (celsius>(eco_m_temp+1.5)){
    caldaia_s = 0;
    }               
  if (celsius<(eco_m_temp-1.5)){
    caldaia_s = 1;
    }
  }
 if (caldaia_s == 0){
        if (old_caldaia_s == 1){
            tft.setRotation(2);
      tft.fillRect(104, 195, 30, 80, BLACK);
      tft.setRotation(3);
      tft.setCursor(215, 115);
      tft.setTextColor(ILI9341_LIGHTGREY);  tft.setTextSize(2);
      tft.println("OFF");
      old_caldaia_s = 0;
      //Serial.print(("2"));
      delay(400);
      
      }
     }
     
  if (caldaia_s == 1){
        if (old_caldaia_s == 0){
      tft.setRotation(2);
      tft.fillRect(104, 195, 30, 80, BLACK);
      tft.setRotation(3);
      tft.setCursor(215, 115);
      tft.setTextColor(RED);  tft.setTextSize(2);
      tft.println("ON");
      old_caldaia_s = 1;
      //Serial.print(("3"));
      delay(400);
      }
     }    
}

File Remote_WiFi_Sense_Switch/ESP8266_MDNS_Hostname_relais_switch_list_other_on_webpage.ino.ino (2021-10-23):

// esp8266 relais switch config portal mdns http//?????.local hostnames
// i noticed that my sonoffs are ESP8285 but it programs well with => generic ESP8266 settings of arduino ide
//
// does anyone know howto add an OTA button on the switch webpage???????? (over the air update upgrade switch)
//
// https://www.youtube.com/watch?v=sRqMcyHR-Ls
//
// each switch webpage automaticly linked lists other http://*.local devices on the local network
// no settings hardcoded => all settings configurable in wifimanager
//
//
// pitty android chrome does not do mdns => use bonjourbrowser app for android
// apple does do mdns?
// my raspberry pi does mdns
//
// still working on this code not all done yet
//
// code used from https://github.com/tzapu/WiFiManager/blob/master/examples/Parameters/SPIFFS/AutoConnectWithFSParameters/AutoConnectWithFSParameters.ino
// code used from https://github.com/esp8266/Arduino/blob/master/libraries/ESP8266mDNS/examples/LEAmDNS/mDNS_ServiceMonitor/mDNS_ServiceMonitor.ino
//
// https://www.electronicwings.com/users/LuberthDijkman/projects/1337/smart-thermostat-art-the-best-nest-thing
//
// https://github.com/ldijkman/ART-ESP32-Touch-TFT-Thermostat/blob/main/test/art_test_1/Remote_WiFi_Sense_Switch/ESP8266_MDNS_Hostname_relais_switch.ino.ino
//
// https://oshwlab.com/l.dijkman/esp32-dev-kit-38-pin-to-spi-touch-tft
// https://github.com/ldijkman/ART-ESP32-Touch-TFT-Thermostat
// http://www.Arduino.TK
//
// https://m.facebook.com/groups/2643123052617990
// https://www.facebook.com/groups/esp32smartthermostat
//
// GNU General Public License,
// which basically means that you may freely copy, change, and distribute it,
// but you may not impose any restrictions on further distribution,
// and you must make the source code available.
//
// keep above message intact?

#include <FS.h>                   // this needs to be first, or it all crashes and burns...
#include <WiFiManager.h>          // https://github.com/tzapu/WiFiManager

#ifdef ESP32
#include <SPIFFS.h>
#endif

#include <ArduinoJson.h>          // https://github.com/bblanchon/ArduinoJson
#include <ESP8266WiFi.h>
#include <ESP8266mDNS.h>

#include <WiFiClient.h>
#include <ESP8266WebServer.h>

WiFiServer server(80);

//define your default values here, if there are different values in config.json, they are overwritten.
char mdns_hostname[40] = "UniqueRoomName";
char relaispin[5] = "12";                     // should be byte or int ???
char buttonpin[5] = "0";                      // should be byte or int ???
char statusledpin[5] = "13";                  // should be byte or int ???
                                         // this should be done easier
int intrelaispin;                             // for char string to int
int intbuttonpin;                             // for char string to int  
int intstatusledpin;                          // for char string to int

int value = LOW;
/*
   Global defines and vars
*/

#define SERVICE_PORT                                    80                                  // HTTP port

#ifndef STASSID
#define STASSID ""
#define STAPSK  ""
#endif
//const char*                                    ssid                    = STASSID;
//const char*                                    password                = STAPSK;

char*                                          pcHostDomain            = 0;        // Negotiated host domain
bool                                           bHostDomainConfirmed    = false;    // Flags the confirmation of the host domain
MDNSResponder::hMDNSService                    hMDNSService            = 0;        // The handle of the http service in the MDNS responder
MDNSResponder::hMDNSServiceQuery               hMDNSServiceQuery       = 0;        // The handle of the 'http.tcp' service query in the MDNS responder

const String                                   cstrNoHTTPServices      = "Currently no 'http.tcp' services in the local network!<br/>";
String                                         strHTTPServices         = cstrNoHTTPServices;

//flag for saving data
bool shouldSaveConfig = false;

//callback notifying us of the need to save config
void saveConfigCallback () {
  Serial.println("Should save config");
  shouldSaveConfig = true;
}

void setup() {
  // put your setup code here, to run once:
  Serial.begin(115200);
  Serial.println();

  //clean FS, for testing              or just program with => all flash contents?
  //SPIFFS.format();

  //read configuration from FS json
  Serial.println("mounting FS...");

  if (SPIFFS.begin()) {
    Serial.println("mounted file system");
    if (SPIFFS.exists("/config.json")) {
      //file exists, reading and loading
      Serial.println("reading config file");
      File configFile = SPIFFS.open("/config.json", "r");
      if (configFile) {
        Serial.println("opened config file");
        size_t size = configFile.size();
        // Allocate a buffer to store contents of the file.
        std::unique_ptr<char[]> buf(new char[size]);

        configFile.readBytes(buf.get(), size);
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

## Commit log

2020-12-09 Create ESP32 TFT backlight brightness PWM
2020-12-09 Create ESP32 RTC DS3231 RealTimeClock
2020-12-09 Create ESP32 LDR light sensor analog input
2020-12-09 Create ESP32 Passive Buzzer Test analog output
2020-12-09 Rename ESP32 Passive Buzzer Test analog output to ESP32 Passive Buzzer Test PWM output
2020-12-09 Create ESP32 Relais Test output
2020-12-09 Create ESP32 NTC Thermistor analog read test
2020-12-09 Rename ESP32 LDR light sensor analog input to ESP32 LDR light sensor analog input.ino
2020-12-09 Rename ESP32 NTC Thermistor analog read test to ESP32 NTC Thermistor analog read test.ino
2020-12-09 Rename ESP32 Passive Buzzer Test PWM output to ESP32 Passive Buzzer Test PWM output.ini
2020-12-09 Rename ESP32 Passive Buzzer Test PWM output.ini to ESP32 Passive Buzzer Test PWM output.ino
    [ESP32 Passive Buzzer Test PWM output.ino]
2020-12-09 Rename ESP32 RTC DS3231 RealTimeClock to ESP32 RTC DS3231 RealTimeClock.ino
2020-12-09 Rename ESP32 Relais Test output to ESP32 Relais Test output.ino
2020-12-09 Rename ESP32 TFT backlight brightness PWM to ESP32 TFT backlight brightness PWM.ino
2020-12-09 Update ESP32 RTC DS3231 RealTimeClock.ino
2020-12-09 Update ESP32 LDR light sensor analog input.ino
2020-12-09 Update ESP32 NTC Thermistor analog read test.ino
2020-12-09 Update ESP32 Relais Test output.ino
2020-12-09 Update ESP32 TFT backlight brightness PWM.ino
2020-12-09 Update ESP32 Passive Buzzer Test PWM output.ino
    [ESP32 Passive Buzzer Test PWM output.ino]
2020-12-09 Create ESP32 Read Write variables to SPIFFS.ino
2020-12-09 Update ESP32 Read Write variables to SPIFFS.ino
